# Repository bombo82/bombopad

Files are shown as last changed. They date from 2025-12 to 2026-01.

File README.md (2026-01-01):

# BomboPad

BomboPad is an open-source, versatile 12-key macropad featuring dual rotary encoders and display support. Designed with
a focus on flexibility, it supports both wired and wireless configurations.

This repository contains the hardware design files, including electrical schematics and PCB layouts.

## Key Features

The current hardware version (**v0.3**) includes:

- **12 keys**: Designed for Kailh Choc v1 low-profile switches.
- **Dual Rotary Encoders**: Supports EC11 or EVQWGD001 encoders.
- **Display Support**: Compatible with SSD1306 128x32 OLED or Nice!View displays.
- **Microcontroller Compatibility**:
    - **Pro Micro** (or compatible) for wired builds.
        - **ATmega32U4**: Fully tested and regularly used.
        - **RP2040**: Functionality verified, but not exhaustively tested.
    - **Nice!Nano** (or compatible) for wireless Bluetooth builds.
- **Battery Management**: Optional Li-Po battery and dedicated power switch for wireless operation.

## Getting Started (v0.3)

To build your own BomboPad, follow these steps:

### Hardware Requirements

- **PCB**: You can order the PCB using the provided [Gerber files](./gerbers/v0.3).
- **Components**: Refer to the **[Bill of Materials (BOM)](./schematics/v0.3/BOM.md)** for a complete list of required
  parts (switches, encoders, diodes, etc.).
- **Microcontroller**: Pro Micro (ATmega32U4 or RP2040) or Nice!Nano compatible.

### Assembly

The electrical schematics and PCB layout files are available in the **[schematics/](./schematics/v0.3)** directory (
KiCad format).

### Firmware

Choose the firmware that best fits your needs:

- **[QMK Firmware](https://github.com/bombo82/qmk_firmware/blob/bombopad/keyboards/handwired/bombopad/readme.md)**: Best
  for wired builds using a Pro Micro.
- **[VIAL Firmware](https://github.com/bombo82/vial-qmk/blob/bombopad/keyboards/handwired/bombopad/readme.md)**: Best
  for wired builds using a Pro Micro. Supports advanced features using VIAL for real-time configuration. See
  the firmware dedicate [release page](https://github.com/bombo82/vial-qmk/releases) for pre-compiled binaries.
- **[ZMK Firmware](https://github.com/bombo82/zmk-bombopad)**: Recommended for wireless builds using a Nice!Nano.

## Project Structure

- **`gerbers/`**: Production-ready Gerber files for PCB manufacturing.
- **`schematics/`**: KiCad project files, including schematics and PCB layout.
- **`BOM.md`**: Detailed Bill of Materials for the current hardware version.

## Version History

Summary of hardware evolution:

- **v0.3 (current)**
    - First version with PCB
    - Wired build using ProMicro compatible microcontroller with QMK or VIAL firmware
    - Wireless build using Nice!Nano compatible microcontroller with ZMK firmware
    - Kailh Choc v1 low-profile switch
    - EC11 rotary encoders or EVQWGD001 encoders
    - Optional display: SSD1306 128x32 on ProMicro microcontroller or Nice!View on Nice!Nano
    - Optional Lipo battery and power switch, depends on microcontroller capabilities
- **v0.2 (not compatible with QMK)**
    - Prototype on a solderless breadboard and a stripboard
    - Use expensive microcontroller and display
    - Bluetooth module and battery management module are integrate inside microcontroller
    - Shares the switch and encoders stripboard with v0.0
    - Disassembled to reuse some parts (microcontroller and display) to my own build of v0.3
- **v0.1 (never built)**
    - Scrapped at the design stage and never built
- **v0.0**
    - Initial prototype on a solderless breadboard and a stripboard
    - Low cost compoments
    - MX switch, EC11 rotary encoders, SSD1306 OLED 128x64 Pixel I2C
    - External HC-06 Bluetooth serial UART module

## Help & Contributions

Bug reports, suggestions, and contributions are welcome! Please
use [GitHub Issues](https://github.com/bombo82/bombopad/issues)
and [Discussions](https://github.com/bombo82/bombopad/discussions) for any feedback.

## Authors

- **Gianni Bombelli (bombo82)** - [GitHub Profile](https://github.com/bombo82)

## Licenses

Documentation are licensed under GNU Free Documentation License as published by the Free Software Foundation, either
version 1.3 of the License, or (at your option) any later version.

Source code are licensed under GNU General Public License as published by the Free Software Foundation, either version 3
of the License, or (at your option) any later version.

Hardware design and all related things are licensed under CERN Open Hardware Licence as published by the CERN, either
version 2 of the Licence, or (at your option) any later version.

## License Disclaimer

Copyright (C) 2024-2025 Gianni Bombelli <bombo82@giannibombelli.it>

Permission is granted to copy, distribute and/or modify this document
under the terms of the GNU Free Documentation License, Version 1.3
or any later version published by the Free Software Foundation;
with no Invariant Sections, no Front-Cover Texts, and no Back-Cover Texts.

You should have received a copy of the GNU Free Documentation License
along with this program. If not, see <https://www.gnu.org/licenses/fdl-1.3.html>.

## Acknowledgements

Special thanks to [Arialdo](https://github.com/arialdomartini) for introducing me to the world of custom mechanical
keyboards.

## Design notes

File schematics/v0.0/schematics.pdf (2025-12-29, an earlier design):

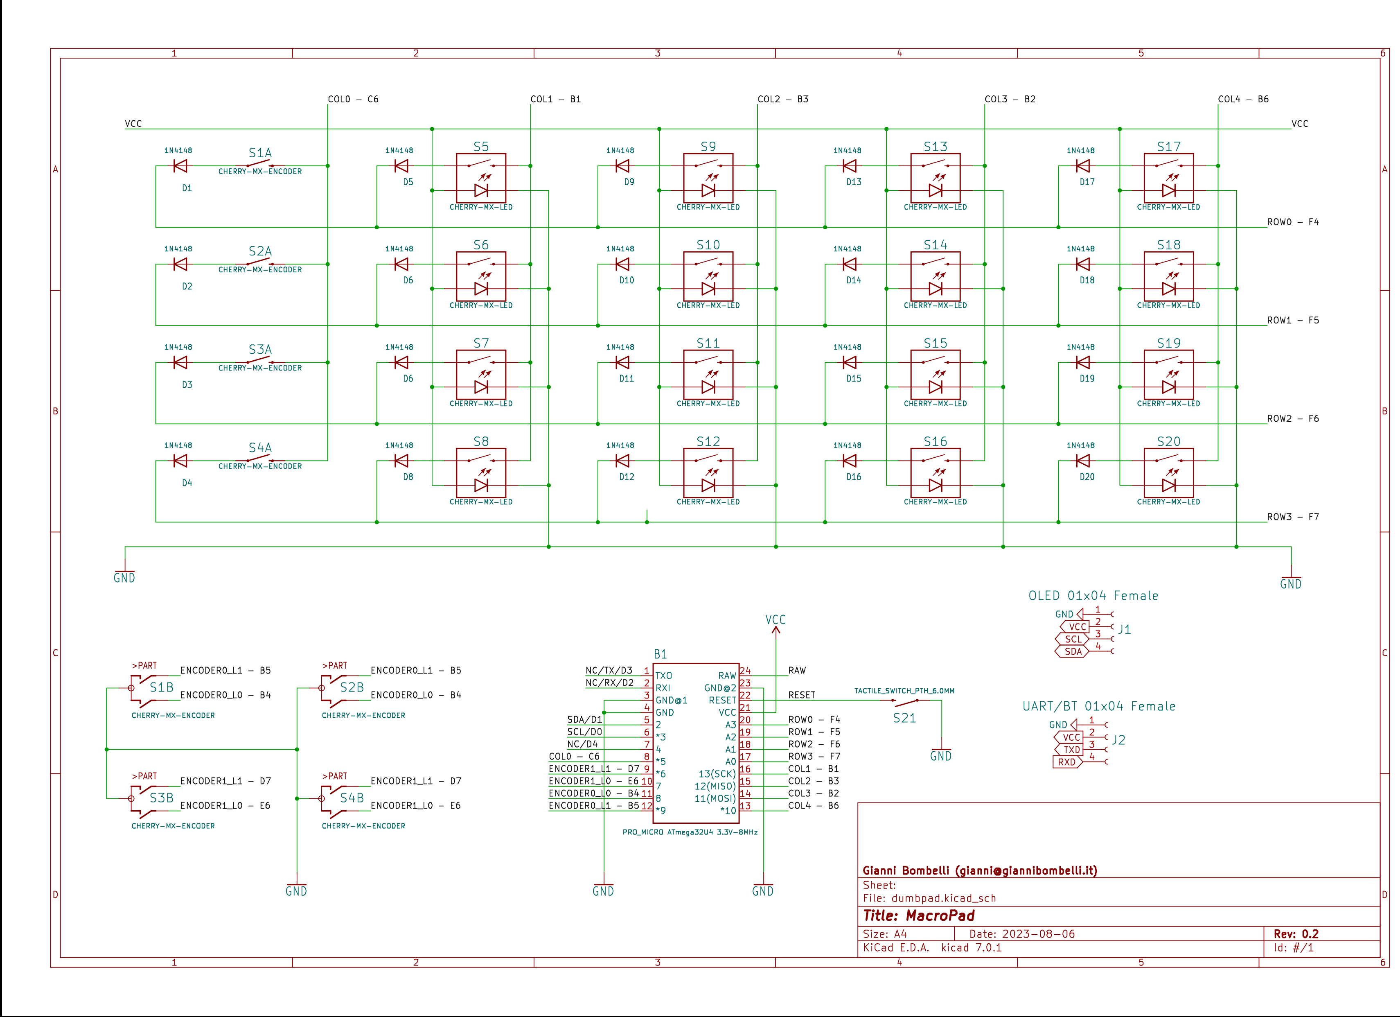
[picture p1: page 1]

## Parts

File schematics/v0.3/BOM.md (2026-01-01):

# Bill of Materials (BOM) - BomboPad v0.3

This Bill of Materials is compliant with OSHWA (Open Source Hardware Association) specifications.

## Main Components

| Designator | Description | Quantity | Footprint | Manufacturer | Part Number |
|---|---|---|---|---|---|
| D1-D12 | Switching Diode | 12 | SOD-123 / Through-hole | Generic | 1N4148W |
| J1 | Battery Connector 2-pin (Optional) | 1 | Molex PicoBlade 1.25mm | Molex | 53048-0210 |
| J2 | Battery Connector 3-pin (Optional) | 1 | Molex PicoBlade 1.25mm | Molex | 53048-0310 |
| MCU1 | Microcontroller Module | 1 | Pro Micro / Nice!Nano  | Generic / Nice Technologies | Pro Micro / Nice!Nano |
| Display | Display Module (Optional) | 1 | niceview_headers | Generic / Nice Technologies | SSD1306 128x32 / Nice!View |
| ROL1, ROL2 | Encoder (Optional) | 2 | EVQWGD001 | Panasonic | EVQWGD001 |
| ROT1, ROT2 | Encoder (Optional) | 2 | EC11 | Generic | EC11 |
| S1-S10 | Low Profile Switches | 10 | Kailh Choc v1 (PG1350) | Kailh | PG1350 |
| S11-S12 | Low Profile Switches (Optional) | 2 | Kailh Choc v1 (PG1350) | Kailh | PG1350 |
| S13 | Reset Button | 1 | 6x6mm Tactile Switch | Generic | SW_Push_1P1T |
| SW15 | Power Switch (Slide) | 1 | DPDT Angled | Generic | JS202011AQN |

## Notes

- **Display**: The OLED (SSD1306 128x32) and Memory Display (Nice!View) are both optional and mutually exclusive
  alternatives. Choose one based on your microcontroller: the OLED is typically used with Pro Micro, while the Nice!View
  is designed for Nice!Nano.
- **Encoders**: The EC11 rotary encoders and EVQWGD001 roller encoders are optional and mutually exclusive
  alternatives. If neither type of encoder is installed, it is recommended to use 2 additional Kailh Choc v1 switches
  (S11 and S12) instead.
- **Switches**: S11 and S12 can be either the integrated push-buttons of the encoders or two standard Kailh Choc v1
  switches if no encoders are used.
- **Microcontroller**:
    - Use a Pro Micro for wired setups (USB-C recommended):
        - MCU with `ATmega32U4` processor is fully tested and regularly used.
        - MCU with `RP2040` processor is verified and works fine, but not exhaustively tested.
    - Use a Nice!Nano compatible for wireless setups:
        - Nice!Nano v2 MCU is fully tested and regularly used.
        - SuperMini NRF52840 MCU is verified and works fine, but not exhaustively tested.
- **Diodes**: Any 1N4148 diode will work. Diodes can be SMD (SOD-123 package) or through-hole.

## License

Copyright (C) 2024-2025 Gianni Bombelli <bombo82@giannibombelli.it>

This document is part of the BomboPad hardware design and is licensed under CERN Open Hardware Licence as published by
the CERN, either version 2 of the Licence, or (at your option) any later version.

You may redistribute and modify this source and make products using it under the terms of the CERN-OHL-S
v2 (https://ohwr.org/cern_ohl_s_v2.txt).

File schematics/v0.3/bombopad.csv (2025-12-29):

Id | Designator | Footprint | Quantity | Designation | Supplier and ref
1 | D1,D2,D3,D4,D5,D6,D7,D8,D9,D10,D11,D12 | ComboDiode | 12
2 | J1 | Molex_PicoBlade_53048-0210_1x02_P1.25mm_Horizontal | 1 | Conn_01x02
3 | J2 | Molex_PicoBlade_53048-0310_1x03_P1.25mm_Horizontal | 1 | Conn_01x03
4 | MCU1 | ProMicro | 1
5 | Nice!View1 | niceview_headers | 1
6 | ROL1,ROL2 | RollerEncoder_Panasonic_EVQWGD001 | 2
7 | ROT1,ROT2 | rotary_encoder | 2
8 | S13 | SW_Push_1P1T_NO_6x6mm_H9.5mm | 1 | SW_Push_Dual_x2
9 | S1,S2,S3,S4,S5,S6,S7,S8,S9,S10 | PG1350 | 10
10 | SW15 | SW_CK_JS202011AQN_DPDT_Angled | 1 | SW_DPDT_x2

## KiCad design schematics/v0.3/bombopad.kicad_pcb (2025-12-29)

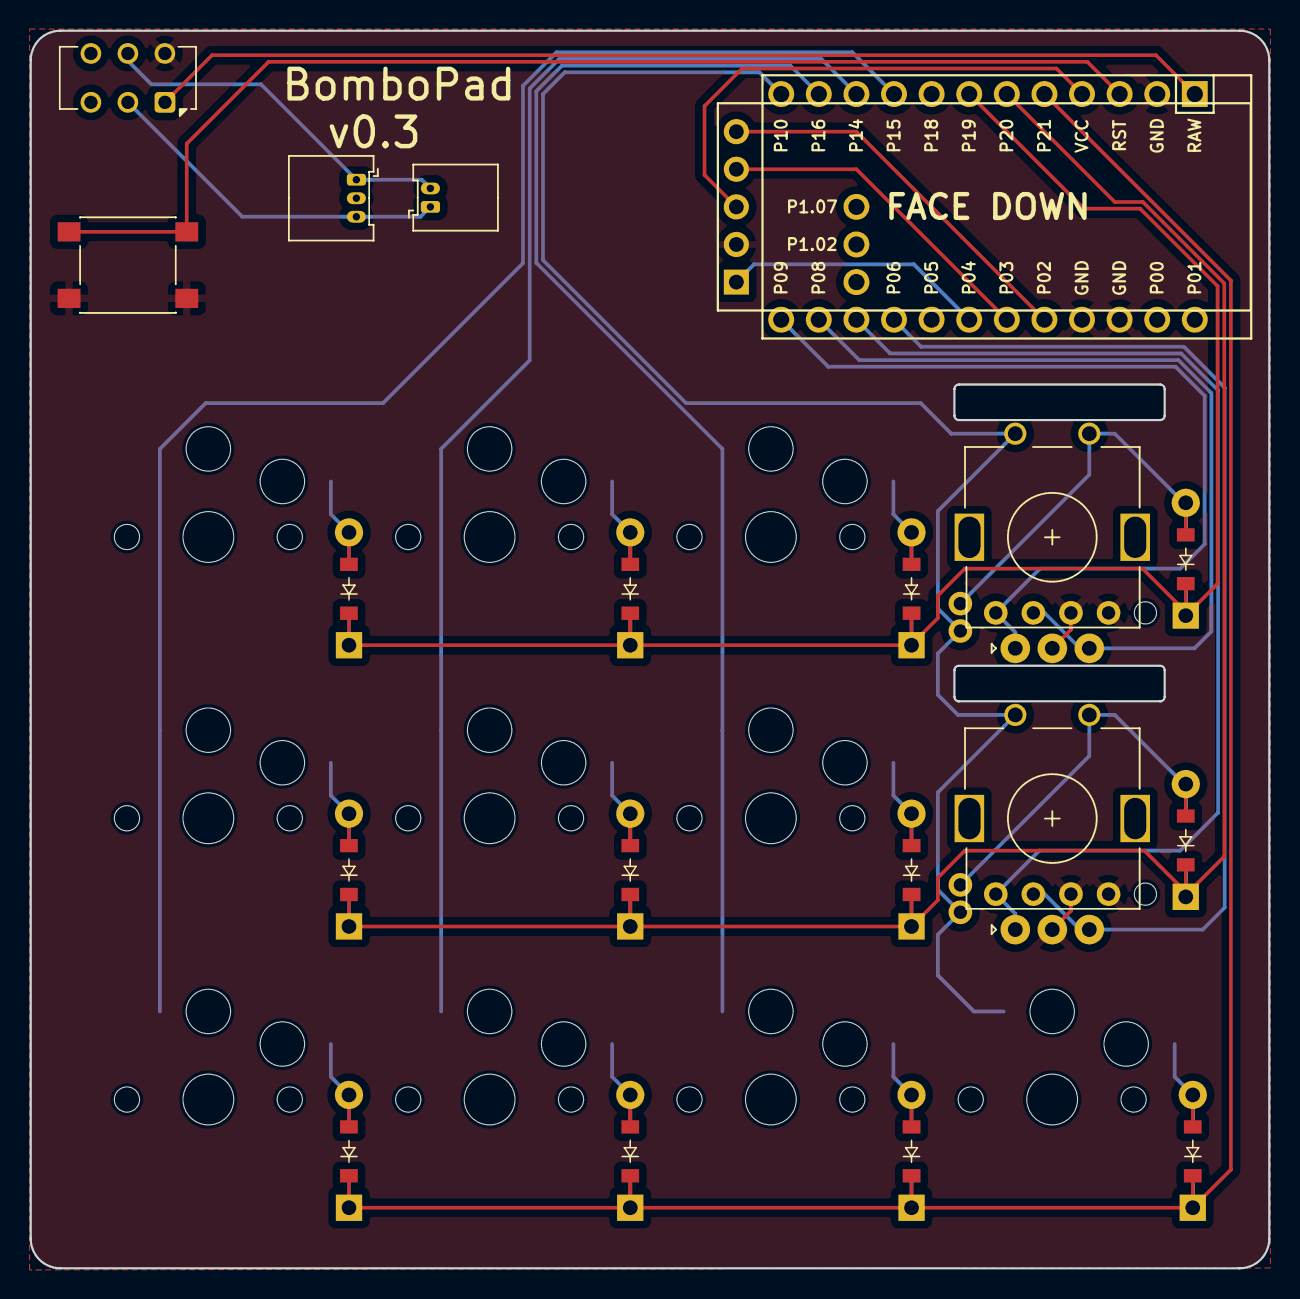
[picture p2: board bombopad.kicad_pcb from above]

Board: 2 copper layers, 83.7 x 83.6 mm, 32 parts (0 on the bottom side), 32 nets.

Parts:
D1, D2, D3, D4, D5, D6, D7, D8, D9, D10, D11, D12: ComboDiode
J1: Conn_01x02; Molex_PicoBlade_53048-0210_1x02_P1.25mm_Horizontal
J2: Conn_01x03; Molex_PicoBlade_53048-0310_1x03_P1.25mm_Horizontal
MCU1: ProMicro
Nice!View1: niceview_headers
ROL1, ROL2: RollerEncoder_Panasonic_EVQWGD001
ROT1, ROT2: rotary_encoder
S1, S2, S3, S4, S5, S6, S7, S8, S9, S10: PG1350
S13: SW_Push_Dual_x2; SW_Push_1P1T_NO_6x6mm_H9.5mm
SW15: SW_DPDT_x2; SW_CK_JS202011AQN_DPDT_Angled

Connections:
+BATT: J1.1, J2.3, SW15.2 (B)
-BATT: J1.2, J2.1, SW15.5 (B)
GND: MCU1.2, MCU1.15, MCU1.16, Nice!View1.2, ROL1.C, ROL1.D, ROL2.C, ROL2.D, ROT1.C, ROT2.C, S13.1 (C), SW15.6 (C)
P2: MCU1.17, Nice!View1.5
P3: MCU1.18, Nice!View1.4
P4: MCU1.19, Nice!View1.1
P6: MCU1.21, ROL2.B, ROT2.B
P7: MCU1.22, ROL2.A, ROT2.A
P8: MCU1.23, ROL1.B, ROT1.B
P9: MCU1.24, ROL1.A, ROT1.A
P10: MCU1.12, ROL1.S1, ROL2.S1, ROT1.1, ROT2.1, S10.1
P14: MCU1.10, S4.1, S5.1, S6.1
P15: MCU1.9, S1.1, S2.1, S3.1
P16: MCU1.11, S7.1, S8.1, S9.1
P19: D3.1, D6.1, D9.1, D12.1, MCU1.7
P20: D2.1, D5.1, D8.1, D11.1, MCU1.6
P21: D1.1, D4.1, D7.1, D10.1, MCU1.5
RAW: MCU1.1, SW15.1 (A)
RST: MCU1.3, S13.2 (D)
VCC: MCU1.4, Nice!View1.3
index_bottom: D7.2, S7.2
index_home: D8.2, S8.2
index_top: D9.2, S9.2
middle_bottom: D4.2, S4.2
middle_home: D5.2, S5.2
middle_top: D6.2, S6.2
ring_bottom: D1.2, S1.2
ring_home: D2.2, S2.2
ring_top: D3.2, S3.2
thumb_bottom: D10.2, S10.2
thumb_home: D11.2, ROL2.S2, ROT2.2
thumb_top: D12.2, ROL1.S2, ROT1.2

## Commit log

2024-10-12 final v0.3 schematics and gerber files
    [bombopad-B_Cu.gbr, bombopad-B_Mask.gbr, bombopad-B_Paste.gbr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]
2024-10-13 use of plular in the name of directories
    [bombopad-B_Cu.gbr, bombopad-B_Mask.gbr, bombopad-B_Paste.gbr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]
2025-12-29 add BOM and CSV files for BomboPad v0.3 schematics
    [bombopad.csv]
2025-12-29 add license notice
    [bombopad.kicad_pcb]
2025-12-29 add schematics and project files for BomboPad v0.1 (only for historical reasons)
    [bombopad_oled-battery-bt.kicad_sch]
2025-12-29 add schematics (pdf format) for BomboPad v0.0 (only for historical reasons)
2025-12-30 Update BOM and documentation: clarify MCU compatibility and other minor changes.

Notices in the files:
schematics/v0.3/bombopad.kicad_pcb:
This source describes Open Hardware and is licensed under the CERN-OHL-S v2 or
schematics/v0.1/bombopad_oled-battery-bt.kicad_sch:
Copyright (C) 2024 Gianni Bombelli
